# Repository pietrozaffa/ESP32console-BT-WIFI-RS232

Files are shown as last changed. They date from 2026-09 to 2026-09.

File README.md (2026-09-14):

# Pi_Zaff — Wireless Console Server (Console ESP32)

Server di console **seriale over WiFi / Bluetooth** su ESP32.

Colleghi l'ESP32 alla porta **console RS-232** di un router, switch, firewall,
UPS o qualsiasi apparato con console seriale, e da quel momento ci accedi senza
filo:

- **via WiFi** — client Telnet (porta 23) *oppure* terminale live nel browser
- **via Bluetooth** — porta COM virtuale (SPP), come un normale adattatore
  USB-seriale ma wireless

Alimentazione a **batteria 18650**, 4 LED di stato, un solo pulsante. Nessun PC
sempre acceso attaccato all'apparato per leggerne la console.

---

## Contenuto del repository

| Percorso | Cosa contiene |
|---|---|
| `Pi_Zaff_v5_0_STABLE/` | Firmware **corrente** (banner interno: v6.0) — Telnet + GUI web + terminale WebSocket + storico connessioni + mDNS + OTA |
| `Pi_Zaff_v5_0_ROLLBACK/` | Firmware **v5.0**, versione di ripiego: stesso hardware e pinout, ma senza terminale WebSocket / storico / mDNS. Da usare solo se la v6.0 dà problemi |
| `PiZaff_Schema_Collegamenti.html` | Schema dei collegamenti (apri nel browser) |
| `PiZaff_Schema_LED.html` | Legenda dei 4 LED |
| `ESPCLI.3mf` | Case per stampa 3D (progetto slicer) |

---

## Hardware

- **ESP32 classico** (WROOM-32 / DevKit) — serve il **Bluetooth classico (SPP)**,
  quindi **non** ESP32-S3/C3/C6 che ne sono privi
- **MAX3232** (adattatore livelli TTL ↔ RS-232) sulla UART2 verso l'apparato
- Batteria **18650** con partitore di tensione verso GPIO34
- 4 LED + resistenze
- 1 pulsante (tra GPIO32 e GND)

### Pinout

```
LED_ACT  = GPIO25      flash sul passaggio di dati
LED_WIFI = GPIO26      modalità WiFi: lampeggia (nessun client) / fisso (client connesso)
LED_BT   = GPIO27      modalità BT:   lampeggia (nessun client) / fisso (client connesso)
LED_BATT = GPIO33      lampeggio di warning batteria

UART2 verso MAX3232:   RX = GPIO16   TX = GPIO17
Batteria 18650 (part.): GPIO34
Pulsante modalità:      GPIO32  → GND (pull-up interno)
```

Schema completo in `PiZaff_Schema_Collegamenti.html`, legenda LED in
`PiZaff_Schema_LED.html`.

---

## Compilazione e flash (Arduino IDE)

Sono sketch `.ino`, si compilano con **Arduino IDE** (o arduino-cli).

1. **Boards Manager** → installa *esp32 by Espressif Systems*.
2. **Tools → Board** → `ESP32 Dev Module`.
3. **Tools → Partition Scheme** → **`Minimal SPIFFS (1.9MB APP with OTA)`**
   (o comunque uno schema **con OTA**: il firmware include `Update.h` per
   l'aggiornamento via web).
4. Solo per `Pi_Zaff_v5_0_STABLE` (v6.0): installa la libreria
   **`WebSockets` di Markus Sattler (arduinoWebSockets / Links2004)** dal
   Library Manager. La versione ROLLBACK non richiede librerie esterne.
5. Apri `Pi_Zaff_v5_0_STABLE/Pi_Zaff_v5_0_STABLE.ino`, seleziona la porta,
   **Upload**.
6. Monitor seriale a **115200** baud per vedere il log di boot.

Aggiornamenti successivi si possono fare **via web** (OTA, vedi sotto) senza
ricollegare l'USB.

---

## Primo collegamento

### Le due modalità

Il dispositivo parte in **una sola** modalità alla volta, scelta col pulsante:

| Modalità | Cosa attiva | Heap libera |
|---|---|---|
| **MODE_WIFI** (default) | Access Point + eventuale STA + Telnet + GUI web + terminale WebSocket + mDNS + OTA | ~140 KB |
| **MODE_BT** | Solo Bluetooth SPP (COM virtuale Windows/Android). WiFi completamente spento. Nessuna GUI | ~100 KB |

**Pulsante GPIO32:**

- **Pressione lunga (> 1.5 s)** a dispositivo acceso → cambia modalità e
  riavvia
- **Tenuto premuto all'accensione** → recovery: forza **MODE_WIFI** (via
  d'uscita se ci si è chiusi fuori in BT)

### In WiFi

1. Connettiti all'access point:
   - SSID **`ConsoleESP32`** · password **`12345678`**
2. Apri **http://192.168.4.1** oppure **http://pizaff.local**
3. Dalla **GUI web**:
   - imposta il **baud rate** della console dell'apparato (9600 default)
   - opzionale: SSID/password della **tua rete** (STA) per raggiungere il
     dispositivo senza doverti agganciare al suo AP
   - opzionale: **password Telnet** (`console` di default) e se richiederla
   - **`/term`** → terminale live nel browser (WebSocket su porta 81, con
     scrollback recente in RAM da 8 KB)
   - home page → stato: RSSI client AP e link STA, motivo dell'ultimo reset,
     **storico ultime 20 connessioni** Telnet/BT
4. In alternativa alla GUI: client **Telnet** su `192.168.4.1` **porta 23**.

### In Bluetooth

1. Pressione lunga sul pulsante per passare a MODE_BT (si riavvia).
2. Accoppia il dispositivo **`ConsoleESP32`** da Windows/Android.
3. Apri la **porta COM virtuale** (SPP) con PuTTY / minicom / screen ai baud
   impostati.

### Baud rate supportati

`9600` · `19200` · `38400` · `57600` · `115200`
(impostati dalla GUI web e salvati in NVS; persistono al riavvio).

---

## Endpoint web (MODE_WIFI)

| Metodo | Path | Funzione |
|---|---|---|
| GET  | `/` | Home page: stato, storico connessioni, RSSI, reset reason |
| POST | `/save` | Salva configurazione (SSID/pass AP+STA, baud, telnet, nome BT) |
| GET  | `/status` | Stato in forma compatta |
| GET  | `/term` | Terminale live nel browser (WebSocket porta 81) |
| GET  | `/term-snapshot` | Snapshot dello scrollback corrente |
| GET  | `/ledtest` | Accende tutti i LED per qualche secondo |
| POST | `/reboot` | Riavvio |
| POST | `/mode` | Cambia modalità WiFi/BT |
| POST | `/update` | **OTA**: carica un nuovo `.bin` compilato |
| POST | `/factory` | **Reset di fabbrica** (cancella la config in NVS) |

`/reboot`, `/mode`, `/factory` e `/update` richiedono **POST** (un semplice link
GET non deve poter riavviare o resettare il dispositivo). Da terminale:

```bash
curl -X POST http://192.168.4.1/factory      # reset config
curl -X POST http://192.168.4.1/reboot       # riavvio
```

---

## LED di stato

| LED | Significato |
|---|---|
| **LED_ACT** (25) | Flash a ogni passaggio di dati sulla console |
| **LED_WIFI** (26) | MODE_WIFI: lampeggia = nessun client, fisso = client connesso. Spento in MODE_BT |
| **LED_BT** (27) | MODE_BT: lampeggia = nessun client, fisso = client connesso. Spento in MODE_WIFI |
| **LED_BATT** (33) | Lampeggio di warning: più veloce man mano che la batteria scende (soglie 15% / 10% / 5%) |

A batteria **critica** il dispositivo si spegne in modo pulito per non
corrompere la flash.

---

## Come funziona (in breve)

- Un **task dedicato** (`bridgeTask`, core 1) fa da ponte fra la UART e il
  client di rete/BT, con due **ring buffer** separati (client→UART e
  UART→client) senza stato condiviso fra i due lettori.
- Se **nessun client** è connesso, i byte in arrivo dalla console vengono
  scartati subito: niente backlog stantìo consegnato al prossimo che si
  collega.
- Protezioni contro i **client "zombie"** (link caduto senza FIN/RST, tipico
  quando il WiFi sparisce durante un output pesante): dopo N `write()` di fila
  che non consegnano nemmeno un byte, la connessione viene chiusa a forza,
  invece di restare impiantati sul peer morto.
- Il terminale WebSocket gira **solo da `loop()`**, mai dal task ponte, per non
  reintrodurre blocchi nel percorso critico.
- **Watchdog** hardware a 30 s.

Il changelog dettagliato (bug-fix e scelte di design versione per versione) è in
testa a `Pi_Zaff_v5_0_STABLE/Pi_Zaff_v5_0_STABLE.ino`.

---

## Reset di fabbrica

`POST /factory` dalla GUI/curl: cancella la config in NVS e riavvia. Tornano i
default (`ConsoleESP32` / `12345678`, baud 9600, telnet `console`, MODE_WIFI).

---

## Licenza

Copyright (C) 2026 Pietro Zaffarano.

Questo progetto è distribuito con licenza **GNU GPL v3.0**: puoi usarlo,
studiarlo, modificarlo e ridistribuirlo, ma ogni derivato che distribuisci
deve restare open source con la stessa licenza — non può essere chiuso in un
prodotto proprietario né essere fatto passare per opera di qualcun altro.
Testo completo in [LICENSE](LICENSE).

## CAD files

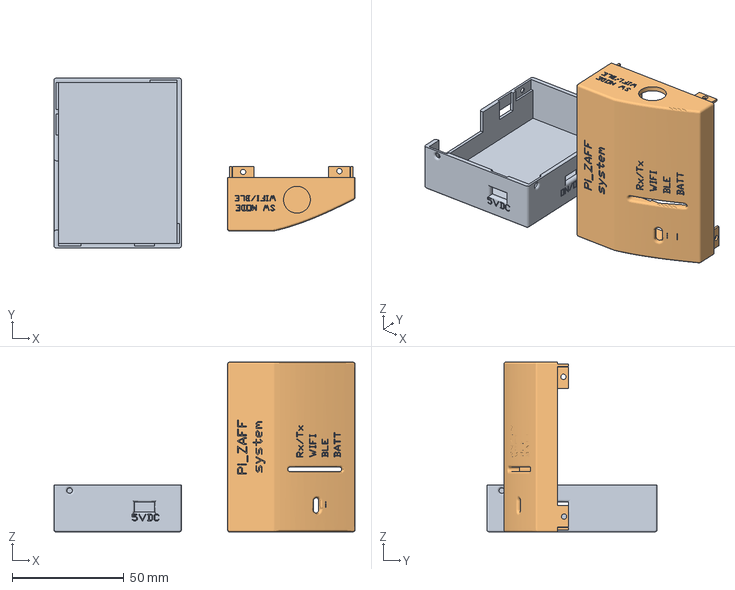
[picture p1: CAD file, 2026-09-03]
ESPCLI.3mf
134.6 x 76.0 x 76.0 mm
Corpo2
Corpo5

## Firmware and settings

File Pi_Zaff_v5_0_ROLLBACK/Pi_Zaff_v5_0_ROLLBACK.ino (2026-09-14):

/*
 * Pi_Zaff System - Wireless Console Server (firmware ESP32)
 * Copyright (C) 2026 Pietro Zaffarano
 *
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
 * You should have received a copy of the GNU General Public License
 * along with this program. If not, see <https://www.gnu.org/licenses/>.
 */

/*
╔══════════════════════════════════════════════════════════════════╗
║         Pi_Zaff System  -  Wireless Console Server               ║
║                  Firmware v5.0 STABILE                           ║
╠══════════════════════════════════════════════════════════════════╣
║  CHANGELOG v5.0 (su v4.9 ROCKSOLID)                              ║
║  ----------------------------------                              ║
║  [BUG-FIX critico] La promessa del comment v4.9 era: "i byte     ║
║    non passati restano in rxQueue per il prossimo ciclo".        ║
║    In realta' la write() ritornava un count parziale e i byte    ║
║    non scritti venivano BUTTATI (la rxQueuePop li aveva gia'     ║
║    rimossi). Su client TCP lenti = output troncato silenzioso.   ║
║    Fix: si controlla il return value di write() e i byte non     ║
║    consegnati vengono ri-accodati in rxQueue per il prossimo     ║
║    ciclo. Compatibile col drop-a-75% del rxQueue, che resta come ║
║    safety net per console troppo lente in modo sostenuto.        ║
║                                                                  ║
║  [BUG-FIX] authBuf della password telnet non veniva azzerato     ║
║    sulla disconnect: il client successivo trovava il prefisso    ║
║    del tentativo precedente. Ora viene resettato.                ║
║                                                                  ║
║  [BUG-FIX] /ledtest chiamava server.handleClient() ricorsivo     ║
║    (rientrante): bomba a orologeria. Ora ritorna subito e i LED  ║
║    restano on fino a ledTestUntil, gestito in updateLEDs().      ║
║                                                                  ║
║  [SAFETY] /factory ora richiede POST (era GET): non si cancella  ║
║    piu' la config con un semplice click su un link malevolo.     ║
║                                                                  ║
║  [SAFETY] handleSave valida le lunghezze SSID/password (rispetta ║
║    i limiti WiFi: SSID<=32, AP pass 8-63).                       ║
║                                                                  ║
║  [PULIZIA] drainSerialToRxQueue scarta i dati UART quando NON    ║
║    c'e' alcun client connesso: niente piu' backlog stantio       ║
║    consegnato al prossimo client al momento del connect.         ║
║                                                                  ║
║  [PULIZIA] vTaskDelay(1) -> vTaskDelay(pdMS_TO_TICKS(1)) per     ║
║    chiarezza (semantica in ms a prescindere dal tick rate).      ║
║                                                                  ║
║  [PULIZIA] Banner di boot e logging coerenti con la versione.    ║
║                                                                  ║
║  NOTA IMPORTANTE: il drop-a-75% di drainSerialToRxQueue resta    ║
║  come da v4.9. E' un feature deliberato per la fluidita' della   ║
║  console e NON e' stato toccato.                                 ║
╠══════════════════════════════════════════════════════════════════╣
║  ARCHITETTURA (invariata da v4.9)                                ║
║  ----------------------------------                              ║
║  Modalita' UNICA al boot, scelta dall'utente tramite pulsante.   ║
║                                                                  ║
║  MODE_WIFI: AP + STA + Telnet + Web GUI + OTA                    ║
║             BT mai inizializzato. Heap libera ~140 KB.           ║
║  MODE_BT  : solo BT SPP (compatibile Windows/Android COM virt.)  ║
║             WiFi completamente spento. Heap libera ~100 KB.      ║
║             Nessuna GUI in questa modalita'.                     ║
║                                                                  ║
║  Pulsante GPIO32:                                                ║
║    long press (>1.5s) a runtime -> toggle mode + reboot          ║
║    premuto al power-on          -> recovery: forza MODE_WIFI     ║
║                                                                  ║
║  LED mode-aware:                                                 ║
║   LED_WIFI: in MODE_WIFI lampeggia (no client) / fisso (client)  ║
║             Spento in MODE_BT.                                   ║
║   LED_BT  : in MODE_BT   lampeggia (no client) / fisso (client)  ║
║             Spento in MODE_WIFI.                                 ║
║   LED_ACT : flash sul passaggio di dati                          ║
║   LED_BATT: lampeggio di warning batteria                        ║
╠══════════════════════════════════════════════════════════════════╣
║  PINOUT                                                          ║
║    LED_ACT=25  LED_WIFI=26  LED_BT=27  LED_BATT=33               ║
║    UART2 verso MAX3232: RX=16  TX=17                             ║
║    Batteria 18650 (partitore): GPIO34                            ║
║    Pulsante modalita': GPIO32 (verso GND, pull-up interno)       ║
╚══════════════════════════════════════════════════════════════════╝
*/

#include <WiFi.h>
#include <WebServer.h>
#include <Preferences.h>
#include "BluetoothSerial.h"
#include <Update.h>
#include <esp_task_wdt.h>
#include <esp_sleep.h>
#include <freertos/FreeRTOS.h>
#include <freertos/task.h>
#include <lwip/sockets.h>     // per setsockopt SO_SNDTIMEO

// ──────────────────────────────────────────────────────────────────
//  DEBUG
// ──────────────────────────────────────────────────────────────────
#define USB_DEBUG_MODE   false     // true = batteria simulata 100%

// ──────────────────────────────────────────────────────────────────
//  PINOUT
// ──────────────────────────────────────────────────────────────────
#define LED_ACT          25
#define LED_WIFI         26
#define LED_BT           27
#define LED_BATT         33

#define UART_RX_PIN      16
#define UART_TX_PIN      17
#define BATT_PIN         34

#define BTN_PIN          32       // pulsante tra GPIO32 e GND

// ──────────────────────────────────────────────────────────────────
//  TIMING / SOGLIE
// ──────────────────────────────────────────────────────────────────
#define LED_ACT_FLASH_MS    30
#define LED_BLINK_PERIOD   500    // lampeggio "in attesa client"
#define BATT_WARN_PCT       15
#define BATT_LOW_PCT        10
#define BATT_CRIT_PCT        5
#define BATT_BLINK_WARN    800
#define BATT_BLINK_LOW     400
#define BATT_BLINK_CRIT    120

#define WDT_TIMEOUT_S       30
#define BATT_READ_INTERVAL  30000UL
#define LOW_BATT_WARN_INT   300000UL
#define LOOP_REPORT_INT     5000UL
#define LOOP_WARN_MS        150

#define BTN_DEBOUNCE_MS     30
#define BTN_LONG_PRESS_MS   1500

// ──────────────────────────────────────────────────────────────────
//  BUFFER
// ──────────────────────────────────────────────────────────────────
#define TX_QUEUE_SIZE      2048
#define TX_HIGH_WATER      (TX_QUEUE_SIZE * 3 / 4)
#define RX_STAGING_SIZE    256
#define UART_RX_BUF        1024
#define UART_TX_BUF        1024
#define BT_TX_CHUNK        16
#define MAX_TELNET_PER_LOOP   128
#define MAX_BT_PER_LOOP       128
#define MAX_UART_TX_PER_LOOP  128

static const uint32_t VALID_BAUDS[] = { 9600, 19200, 38400, 57600, 115200 };
static const size_t   N_VALID_BAUDS = sizeof(VALID_BAUDS)/sizeof(VALID_BAUDS[0]);
static bool isValidBaud(uint32_t b) {
  for (size_t i = 0; i < N_VALID_BAUDS; i++) if (VALID_BAUDS[i] == b) return true;
  return false;
}

// ──────────────────────────────────────────────────────────────────
//  MODALITA' DI BOOT
// ──────────────────────────────────────────────────────────────────
enum BootMode : uint8_t {
  MODE_WIFI = 0,
  MODE_BT   = 1
};
static uint8_t bootMode = MODE_WIFI;

static const char* bootModeName(uint8_t m) {
  return (m == MODE_BT) ? "BT" : "WIFI";
}

// ──────────────────────────────────────────────────────────────────
//  OGGETTI GLOBALI
// ──────────────────────────────────────────────────────────────────
Preferences      prefs;
WebServer        server(80);
BluetoothSerial  SerialBT;
HardwareSerial   ConsoleSerial(2);
WiFiServer       telnetServer(23);
WiFiClient       telnetClient;

// ──────────────────────────────────────────────────────────────────
//  CONFIG
// ──────────────────────────────────────────────────────────────────
String   apSSID, apPassword;
String   staSSID, staPassword;
String   bluetoothName;
String   telnetPassword;
bool     useSTA          = false;
bool     telnetAuthReq   = false;
uint32_t baudRate        = 9600;

// ──────────────────────────────────────────────────────────────────
//  STATO RUNTIME
// ──────────────────────────────────────────────────────────────────
bool          telnetAuthenticated = false;
bool          otaInProgress       = false;
float         battVoltage         = 0.0f;
int           battPercent         = 0;

unsigned long lastBattRead        = 0;
unsigned long lastLowBattWarn     = 0;
unsigned long ledActFlashUntil    = 0;
unsigned long ledBattLastTick     = 0;
bool          ledBattState        = false;

// v5.0: stato globale del LED-test asincrono (sostituisce il busy-loop
// rientrante che chiamava server.handleClient() dentro un handler).
unsigned long ledTestUntil        = 0;

// v5.0: buffer della password telnet a file-scope, cosi' si puo'
// azzerare nel ramo di disconnect (prima era static dentro handleTelnet
// e restava sporco fra una connessione e l'altra).
String        telnetAuthBuf       = "";

IPAddress     apIP(192, 168, 4, 1);
IPAddress     apGW(192, 168, 4, 1);
IPAddress     apMask(255, 255, 255, 0);

// ──────────────────────────────────────────────────────────────────
//  BRIDGE TASK (Core 1, singolo task)
// ──────────────────────────────────────────────────────────────────
static TaskHandle_t   bridgeTaskHandle = NULL;
#define BRIDGE_STACK_SIZE   8192
#define BRIDGE_PRIORITY     3
#define BRIDGE_CORE         1

static volatile unsigned long bridgeMaxTime = 0;

// ──────────────────────────────────────────────────────────────────
//  RING BUFFER 1: txQueue (client RX -> UART TX)
// ──────────────────────────────────────────────────────────────────
static uint8_t           txQueue[TX_QUEUE_SIZE];
static volatile uint16_t txHead = 0;
static volatile uint16_t txTail = 0;

static inline uint16_t txQueueUsed() {
  uint16_t h = txHead, t = txTail;
  return (h >= t) ? (h - t) : (TX_QUEUE_SIZE - (t - h));
}
static inline bool canAcceptMoreData() {
  return txQueueUsed() < TX_HIGH_WATER;
}
static int txQueuePush(const uint8_t* data, int len) {
  int n = 0;
  uint16_t h = txHead;
  while (n < len) {
    uint16_t next = (h + 1) % TX_QUEUE_SIZE;
    if (next == txTail) break;
    txQueue[h] = data[n++];
    h = next;
  }
  txHead = h;
  return n;
}

// ──────────────────────────────────────────────────────────────────
//  RING BUFFER 2: rxQueue (UART RX -> client TX)
// ──────────────────────────────────────────────────────────────────
#define RX_QUEUE_SIZE      4096
static uint8_t             rxQueue[RX_QUEUE_SIZE];
static volatile uint16_t   rxHead = 0;
static volatile uint16_t   rxTail = 0;

static inline uint16_t rxQueueUsed() {
  uint16_t h = rxHead, t = rxTail;
  return (h >= t) ? (h - t) : (RX_QUEUE_SIZE - (t - h));
}

static int rxQueuePush(const uint8_t* data, int len) {
  int n = 0;
  uint16_t h = rxHead;
  while (n < len) {
    uint16_t next = (h + 1) % RX_QUEUE_SIZE;
    if (next == rxTail) break;
    rxQueue[h] = data[n++];
    h = next;
  }
  rxHead = h;
  return n;
}

static int rxQueuePop(uint8_t* out, int maxLen) {
  int n = 0;
  uint16_t t = rxTail;
  while (n < maxLen && t != rxHead) {
    out[n++] = rxQueue[t];
    t = (t + 1) % RX_QUEUE_SIZE;
  }
  rxTail = t;
  return n;
}

// ──────────────────────────────────────────────────────────────────
//  FORWARD DECL
// ──────────────────────────────────────────────────────────────────
void ledActTrigger();
static void saveBootModeAndReboot(uint8_t newMode);

// ──────────────────────────────────────────────────────────────────
//  PULSANTE GPIO32
// ──────────────────────────────────────────────────────────────────
static bool          btnLastRaw       = HIGH;
static bool          btnState         = HIGH;
static unsigned long btnLastChange    = 0;
static unsigned long btnPressStart    = 0;
static bool          btnLongFired     = false;

static void buttonInit() {
  pinMode(BTN_PIN, INPUT_PULLUP);
  delay(2);
  btnLastRaw    = digitalRead(BTN_PIN);
  btnState      = btnLastRaw;
  btnLastChange = millis();
}

static void handleButton() {
  unsigned long now = millis();
  bool raw = digitalRead(BTN_PIN);

  if (raw != btnLastRaw) {
    btnLastRaw    = raw;
    btnLastChange = now;
  }

  if ((now - btnLastChange) > BTN_DEBOUNCE_MS && btnState != btnLastRaw) {
    btnState = btnLastRaw;
    if (btnState == LOW) {
      btnPressStart = now;
      btnLongFired  = false;
    }
  }

  if (btnState == LOW && !btnLongFired && (now - btnPressStart) >= BTN_LONG_PRESS_MS) {
    btnLongFired = true;
    uint8_t newMode = (bootMode == MODE_WIFI) ? MODE_BT : MODE_WIFI;
    Serial.printf("[BTN] long press: %s -> %s\n",
                  bootModeName(bootMode), bootModeName(newMode));
    saveBootModeAndReboot(newMode);
  }
}

static void saveBootModeAndReboot(uint8_t newMode) {
  prefs.begin("cfg", false);
  prefs.putUChar("mode", newMode);
  prefs.end();

  if (bridgeTaskHandle != NULL) {
    vTaskDelete(bridgeTaskHandle);
    bridgeTaskHandle = NULL;
    delay(50);
  }

  for (int i = 0; i < 6; i++) {
    digitalWrite(LED_WIFI, i & 1);
    digitalWrite(LED_BT,   i & 1);
    digitalWrite(LED_ACT,  i & 1);
    digitalWrite(LED_BATT, i & 1);
    delay(120);
    esp_task_wdt_reset();
  }
  digitalWrite(LED_WIFI, LOW);
  digitalWrite(LED_BT,   LOW);
  digitalWrite(LED_ACT,  LOW);
  digitalWrite(LED_BATT, LOW);
  delay(100);
  ESP.restart();
}

// ──────────────────────────────────────────────────────────────────
//  BATTERIA
// ──────────────────────────────────────────────────────────────────
#define BATT_SAMPLES     16
#define BATT_DIVIDER     2.0f
#define BATT_ADC_REF     3.3f
#define BATT_ADC_MAX     4095.0f
#define BATT_CAL_FACTOR  1.07f

static const float battCurveV[] = { 4.20f, 4.00f, 3.80f, 3.70f, 3.60f, 3.40f, 3.00f };
static const int   battCurveP[] = {  100,    85,    60,    40,    20,    10,     0 };
static const int   battCurveN   = 7;

static int voltageToPercent(float v) {
  if (v >= battCurveV[0])              return 100;
  if (v <= battCurveV[battCurveN - 1]) return 0;
  for (int i = 0; i < battCurveN - 1; i++) {
    if (v <= battCurveV[i] && v > battCurveV[i + 1]) {
      float ratio = (v - battCurveV[i + 1]) / (battCurveV[i] - battCurveV[i + 1]);
      return battCurveP[i + 1] + (int)(ratio * (battCurveP[i] - battCurveP[i + 1]));
    }
  }
  return 0;
}

static void readBattery() {
  if (USB_DEBUG_MODE) {
    battVoltage = 4.10f;
    battPercent = 100;
    return;
  }
  long sum = 0;
  for (int i = 0; i < BATT_SAMPLES; i++) sum += analogRead(BATT_PIN);
  float adc = sum / (float)BATT_SAMPLES;
  battVoltage = (adc / BATT_ADC_MAX) * BATT_ADC_REF * BATT_DIVIDER * BATT_CAL_FACTOR;
  battPercent = voltageToPercent(battVoltage);
}

// ──────────────────────────────────────────────────────────────────
//  LED - mode-aware
// ──────────────────────────────────────────────────────────────────
static void setupLEDs() {
  pinMode(LED_ACT,  OUTPUT);
  pinMode(LED_WIFI, OUTPUT);
  pinMode(LED_BT,   OUTPUT);
  pinMode(LED_BATT, OUTPUT);
  const int leds[] = { LED_ACT, LED_WIFI, LED_BT, LED_BATT };
  for (int i = 0; i < 4; i++) { digitalWrite(leds[i], HIGH); delay(120); }
  delay(200);
  for (int i = 0; i < 4; i++) { digitalWrite(leds[i], LOW);  delay(80); }
}

inline void ledActTrigger() {
  digitalWrite(LED_ACT, HIGH);
  ledActFlashUntil = millis() + LED_ACT_FLASH_MS;
}

static void updateLEDs() {
  unsigned long now = millis();

  // v5.0: LED-test asincrono. Se ledTestUntil > 0 forziamo tutti i LED
  // accesi finche' non scade, poi torniamo alla gestione normale.
  // Questo sostituisce il busy-loop che dentro handleLedTest chiamava
  // server.handleClient() ricorsivamente (rientranza vietata).
  if (ledTestUntil > 0) {
    if (now < ledTestUntil) {
      digitalWrite(LED_ACT,  HIGH);
      digitalWrite(LED_WIFI, HIGH);
      digitalWrite(LED_BT,   HIGH);
      digitalWrite(LED_BATT, HIGH);
      return;
    }
    // scaduto: spegni e prosegui con la logica normale.
    // LED_ACT va spento esplicitamente perche' la sua transizione
    // normale dipende dal flash trigger, non da un timer di reset.
    ledTestUntil = 0;
    ledActFlashUntil = 0;
    digitalWrite(LED_ACT, LOW);
  }

  // LED_ACT: spegni dopo il flash
  if (ledActFlashUntil > 0 && now >= ledActFlashUntil) {
    digitalWrite(LED_ACT, LOW);
    ledActFlashUntil = 0;
  }

  // LED_WIFI e LED_BT: dipendono dalla modalita' e dalla presenza di client
  if (bootMode == MODE_WIFI) {
    digitalWrite(LED_BT, LOW);
    bool clientConnesso =
      (WiFi.softAPgetStationNum() > 0) ||
      (telnetClient && telnetClient.connected());
    if (clientConnesso) {
      digitalWrite(LED_WIFI, HIGH);
    } else {
      digitalWrite(LED_WIFI, (now / LED_BLINK_PERIOD) & 1);
    }
  } else { // MODE_BT
    digitalWrite(LED_WIFI, LOW);
    if (SerialBT.hasClient()) {
      digitalWrite(LED_BT, HIGH);
    } else {
      digitalWrite(LED_BT, (now / LED_BLINK_PERIOD) & 1);
    }
  }

  // LED_BATT: warning batteria
  if (battPercent >= BATT_WARN_PCT) {
    digitalWrite(LED_BATT, LOW);
    ledBattState = false;
  } else {
    unsigned long period =
      (battPercent <= BATT_CRIT_PCT) ? BATT_BLINK_CRIT :
      (battPercent <= BATT_LOW_PCT)  ? BATT_BLINK_LOW  : BATT_BLINK_WARN;
    if (now - ledBattLastTick >= period) {
      ledBattState = !ledBattState;
      digitalWrite(LED_BATT, ledBattState ? HIGH : LOW);
      ledBattLastTick = now;
    }
  }
}

static void handleLowBatteryWarning() {
  if (battPercent > 10) return;
  if (millis() - lastLowBattWarn < LOW_BATT_WARN_INT) return;

  char msg[64];
  int len = snprintf(msg, sizeof(msg),
           "\r\n[WARNING] BATTERIA %d%% (%.2fV)\r\n",
           battPercent, battVoltage);
  if (len > 0 && len < (int)sizeof(msg)) {
    rxQueuePush((const uint8_t*)msg, len);
  }
  lastLowBattWarn = millis();
}

static void handleCriticalBatteryShutdown() {
  if (USB_DEBUG_MODE)      return;
  if (otaInProgress)       return;
  if (battVoltage > 3.15f) return;

  Serial.println(F("\n[CRITICAL BATTERY -> DEEP SLEEP]"));

  if (bridgeTaskHandle != NULL) {
    vTaskDelete(bridgeTaskHandle);
    bridgeTaskHandle = NULL;
    delay(50);
  }

  digitalWrite(LED_ACT,  LOW);
  digitalWrite(LED_WIFI, LOW);
  digitalWrite(LED_BT,   LOW);
  digitalWrite(LED_BATT, LOW);
  delay(300);
  if (bootMode == MODE_WIFI) {
    WiFi.disconnect(true);
    WiFi.mode(WIFI_OFF);
  } else {
    SerialBT.end();
  }
  esp_deep_sleep_start();
}

// ──────────────────────────────────────────────────────────────────
//  TELNET IAC PARSER
// ──────────────────────────────────────────────────────────────────
#define IAC          0xFF
#define DONT         0xFE
#define DO           0xFD
#define WONT         0xFC
#define WILL         0xFB
#define SB           0xFA
#define SE           0xF0
#define TELOPT_ECHO  1
#define TELOPT_SGA   3

enum TelnetParseState : uint8_t {
  TN_NORMAL, TN_GOT_IAC, TN_GOT_VERB, TN_SUBNEG
};
static TelnetParseState tnState  = TN_NORMAL;
static uint8_t          tnVerb   = 0;
static bool             tnLastCR = false;

static void sendTelnetInitialNegotiation() {
  static const uint8_t init[] = {
    IAC, WILL, TELOPT_ECHO,
    IAC, WILL, TELOPT_SGA,
    IAC, DO,   TELOPT_SGA,
  };
  rxQueuePush(init, sizeof(init));
}

static void clientOut(const char* s) {
  if (!s) return;
  size_t len = strlen(s);
  if (len > 0) rxQueuePush((const uint8_t*)s, len);
}
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
void loop() {
  static unsigned long loopMaxTime    = 0;
  static unsigned long lastLoopReport = 0;
  unsigned long loopStart = millis();

  esp_task_wdt_reset();

  handleButton();

  if (otaInProgress) {
    delay(1);
    return;
  }

  if (bootMode == MODE_WIFI) {
    server.handleClient();
  }

  updateLEDs();
  handleCriticalBatteryShutdown();

  if (millis() - lastBattRead > BATT_READ_INTERVAL) {
    readBattery();
    lastBattRead = millis();
  }

  unsigned long loopTime = millis() - loopStart;
  if (loopTime > loopMaxTime) loopMaxTime = loopTime;

  if (millis() - lastLoopReport > LOOP_REPORT_INT) {
    if (loopMaxTime > LOOP_WARN_MS || bridgeMaxTime > 50) {
      Serial.printf("[PERF] loop=%lums bridge=%lums txq=%u rxq=%u heap=%u mode=%s\n",
                    loopMaxTime, bridgeMaxTime,
                    txQueueUsed(), rxQueueUsed(),
                    (unsigned)ESP.getFreeHeap(),
                    bootModeName(bootMode));
    }
    loopMaxTime = 0;
    bridgeMaxTime = 0;
    lastLoopReport = millis();
  }

  delay(5);
}

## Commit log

2026-09-03 Initial commit: console ESP32 (Pi_Zaff v5.0)
    Firmware Arduino per la console ESP32 (versioni STABLE e ROLLBACK),
    case OpenSCAD, schemi di collegamento e script di generazione codice.
    [ESPCLI.3mf, PiZaff_Case.scad]
2026-09-03 Aggiunge guida: installazione, collegamento e funzionamento della console ESP32
2026-09-14 Rimuove il generatore di licenze app (repo separata) e aggiunge licenza GPL-3.0
    Il progetto va reso pubblico; genera_codice.py conteneva la chiave segreta
    usata per validare le licenze dell'app Android companion e va tenuto privato.
2026-09-14 Corregge anno di copyright (2026)

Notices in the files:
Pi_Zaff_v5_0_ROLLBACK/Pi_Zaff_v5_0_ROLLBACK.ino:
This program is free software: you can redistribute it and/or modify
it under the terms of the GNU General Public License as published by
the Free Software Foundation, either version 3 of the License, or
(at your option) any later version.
